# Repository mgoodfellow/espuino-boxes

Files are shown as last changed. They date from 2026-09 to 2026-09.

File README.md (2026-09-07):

# ESPuino boxes

Build profiles, wiring notes and printable enclosures for two DIY RFID audio
players built with [ESPuino](https://github.com/biologist79/ESPuino).
Insert a card, play an audiobook, and use the buttons and encoder for playback.

These are community reference builds based on physical boxes. Each profile pins
a firmware revision; compatibility with current upstream branches or other board
variants is not implied. Firmware changes live in the
[ESPuino fork’s `s3-test-all` integration branch](https://github.com/mgoodfellow/ESPuino/tree/s3-test-all),
not in this repository. The build guide starts from that fork/branch, then checks
out the exact recorded revision from the selected profile’s `upstream.lock`.
These older snapshots are retained for reproducibility; they do not follow the
current branch head automatically.

| Profile | Hardware | Storage | LEDs | Bluetooth |
|---|---|---|---|---|
| [s3-proto](boxes/s3-proto/README.md) | ESP32-S3 DevKitC-1 clone **N16R8**, 16MB flash / 8MB octal PSRAM | External SPI microSD | 12 WS2812B, NeoPixelBus LCD/GDMA | Disabled; no Classic Bluetooth |
| [kidbox-lolin-1](boxes/kidbox-lolin-1/README.md) | WeMos LOLIN D32 Pro V2.0.0, **16MB flash**, WROVER PSRAM | Onboard SPI microSD | 12 WS2812B, NeoPixelBus I2S1 | Enabled in the profile |

Both use a MAX98357A mono amplifier, RC522 reader, EC11 encoder and three
buttons. Both documented builds use a **5V USB supply**, without batteries.
The S3 also has notes for an experimental PN5180 reader swap.

## Start here

1. Choose a profile above and check its wiring against your actual board.
2. Follow the [build and first-boot guide](docs/espuino-build-guide.md).
3. Build the pinned firmware before adapting settings to another revision.
4. Try the [enclosure](case/README.md) after the electronics work on the bench.

### ESP32-S3 compilation fails on ESP32-A2DP?

The [S3 PlatformIO override](boxes/s3-proto/platformio-override.ini) sets
`lib_ignore = ESP32-A2DP`, and its settings leave `BLUETOOTH_ENABLE` disabled.
The library exclusion matters: the dependency finder can otherwise build A2DP
although the feature is disabled. The profile also supplies the N16R8 memory
configuration and a fixed toolchain URL. See the
[S3 setup and troubleshooting notes](boxes/s3-proto/README.md).

## Printable case

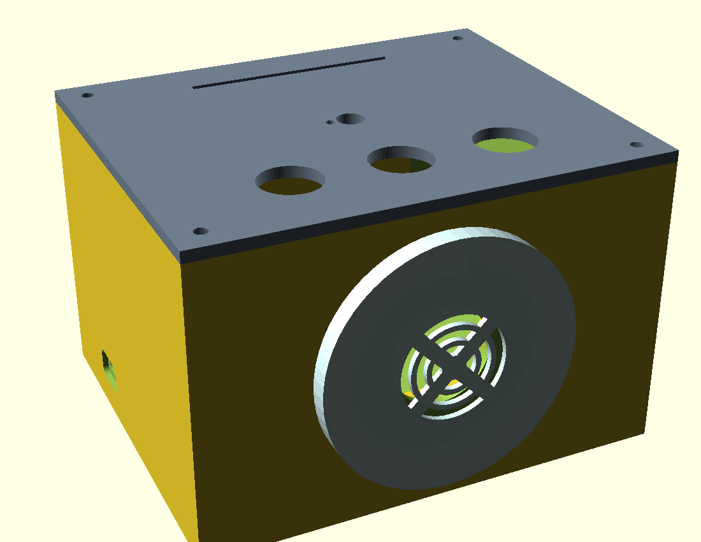
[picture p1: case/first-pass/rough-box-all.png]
CAD preview of the enclosure


The image is a CAD preview. Editable OpenSCAD and STL exports include a card
slot, speaker/ring cover, two carrier layouts and an optional RC522 offset shim.
Carrier mounts fit the measured perfboard assemblies, not bare development-board
mounting holes. Start with the fit coupon and measure your parts.

## What is included

- `boxes/`: build settings, pin maps, firmware revision locks and wiring.
- `deploy.sh`: copies one profile into a separate ESPuino checkout and builds it.
- `docs/`: build instructions and the release verification record.
- `case/`: enclosure source, exports, dimensions and fixings.

Saved Wi-Fi networks, RFID-to-audio mappings and other runtime settings live on
the device. They are not supplied here. Existing runtime settings can override
compiled defaults. Audio files are not included.

## Contributions and scope

Corrections and reports from other builds are welcome. Include the exact board,
profile, firmware commit and a redacted build/boot log. Explain what you tested
on hardware. Please keep wiring specific to a profile and avoid committing
credentials, NVS dumps or personal card mappings.

This is a hobby project, with no promised support schedule. Firmware bugs belong
upstream when reproduced there; profile and enclosure problems belong here.
See [verification and limitations](docs/VALIDATION.md) for the release evidence.

## License and credits

Released under [GNU GPL version 3](LICENSE). Configuration headers are modified
from ESPuino; see [NOTICE.md](NOTICE.md) for attribution and CAD provenance.

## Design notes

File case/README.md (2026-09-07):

# Printable enclosure

A parametric OpenSCAD enclosure with a top card slot, three 16mm buttons, EC11
encoder, speaker and 12-pixel ring. The outer shell is 124 × 102 × 78mm before
the lid and projecting cover. See [measured parts](MEASUREMENTS.md).

Assembly CAD preview

This is a practical first-pass case fitted around two specific perfboard
assemblies. Measure your parts and slice/check the model before printing.
Preview images include development views; use the selected STL and source for
actual geometry. The carrier mount patterns are not bare ESP32 board footprints.

## Files to print

| Part | File | Quantity |
|---|---|---|
| S3 shell, V1 carrier and separate SD mount | [rough-box-shell-v1.stl](first-pass/rough-box-shell-v1.stl) | 1 for S3 |
| D32 shell, V2 carrier and onboard SD | [rough-box-shell-v2.stl](first-pass/rough-box-shell-v2.stl) | 1 for D32 |
| Common lid | [rough-box-top.stl](first-pass/rough-box-top.stl) | 1 |
| Speaker/ring cover | [rough-box-cover.stl](first-pass/rough-box-cover.stl) | 1 |
| Fit coupon | [rough-box-coupon.stl](first-pass/rough-box-coupon.stl) | Print first |
| Optional RC522 offset adapter | [shim instructions](first-pass/rc522-8mm-offset-shim.md) | As needed |

Use translucent material for the cover if you want light through it. Check
orientation, overhangs, wall strength and clearances in your slicer; no universal
printer/material profile is supplied. Check card insertion and RFID reading
before committing to the full assembly.

## Editing and exporting

Open [rough-box.scad](first-pass/rough-box.scad) in OpenSCAD. Select
`part="shell"`, `"top"`, `"cover"` or `"coupon"`; for a shell select
`variant="v1"` (S3) or `"v2"` (D32). Render (F6), then export STL.
`part="all"` is an assembly preview. `variant="both"` is a legacy comparison
layout whose posts interfere with the revised V1 carrier; do not print it for a box.

The [RC522 shim source](first-pass/rc522-8mm-offset-shim.scad) exports separately.
Its offset is adjustable from 8 to 10mm; the supplied STL uses 8mm. It is an
optional retrofit, not a required part of every build.

## Assembly

1. Print the coupon and confirm screw/panel-component fits.
2. Print the appropriate shell, lid and cover.
3. Fit USB breakout, carrier and speaker with the [listed fasteners](first-pass/FIXINGS.md).
4. Slide the RC522 into the coil-end rail and secure its pin end. Use the shim
   instructions if increasing the reader-to-card gap.
5. Route wiring away from screw holes, the card guide and moving controls.
6. Test playback, controls and reliable card reading/removal before closing the lid.

These are hobby enclosure files, not a certified child-safe product. Check that
fasteners, small parts and low-voltage wiring are secured for the intended user.
See [credits and provenance](../NOTICE.md).

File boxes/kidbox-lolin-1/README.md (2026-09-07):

# LOLIN D32 Pro V2.0.0 reference build

USB-powered WeMos LOLIN D32 Pro V2.0.0 with 16MB flash, WROVER PSRAM and
onboard SPI microSD. Uses RC522, MAX98357A, a 12-pixel ring, EC11 and three buttons.

- [Build guide](../../docs/espuino-build-guide.md)
- [Wiring, resistors and wake circuit](wiring.md)
- [Firmware revision](upstream.lock): `1ea941446cd99b495cf6df2a16b6b230b3379f5a`
  from [mgoodfellow/ESPuino](https://github.com/mgoodfellow/ESPuino/commit/1ea941446cd99b495cf6df2a16b6b230b3379f5a).
- Ongoing firmware integration: [`s3-test-all`](https://github.com/mgoodfellow/ESPuino/tree/s3-test-all).
  The lock above selects an older recorded snapshot, not the moving branch head.
- Environment: `lolin_d32_pro` (`HAL=4`), not `lolin_d32_pro_sdmmc_pe`.

The profile includes the upstream HAL 4 map, then overrides the encoder switch
to GPIO22 and uses GPIO32 as a dedicated wake line. Follow the wiring table for
the external resistor and diode requirements. In particular, encoder A/B on
GPIO34/39 need pull-downs to GND; the button on GPIO36 needs a pull-up to 3V3.

Classic Bluetooth is enabled in this profile. Battery measurement and headphone
detection are disabled. LED output uses NeoPixelBus I2S1 in the pinned firmware.
Hardware wiring and fit observations are recorded in the accompanying notes;
see [release validation](../../docs/VALIDATION.md) for the current build checks.

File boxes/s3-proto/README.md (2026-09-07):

# ESP32-S3 DevKitC-1 N16R8 reference build

A USB-powered generic DevKitC-1 clone with 16MB quad flash and 8MB octal PSRAM,
SPI microSD, MAX98357A, RC522, 12-pixel WS2812B ring, EC11 and three buttons.
The directory name `s3-proto` is retained for existing deployment commands.

- [Build guide](../../docs/espuino-build-guide.md)
- [Wiring and hardware caveats](wiring.md)
- [Firmware revision](upstream.lock): `f3eec352659eb7cc195b3059cfd3d398ac1d0412`
  from [mgoodfellow/ESPuino](https://github.com/mgoodfellow/ESPuino/commit/f3eec352659eb7cc195b3059cfd3d398ac1d0412).
- Ongoing firmware integration: [`s3-test-all`](https://github.com/mgoodfellow/ESPuino/tree/s3-test-all).
  The lock above selects an older recorded snapshot, not the moving branch head.
- Environment: `esp32-s3-devkitc-1`, custom pin map (`HAL=99`).

## What the profile supplies

| Setting | Purpose |
|---|---|
| Explicit pioarduino `55.03.38-1` platform URL | Avoids the bare `espressif32` name resolving to a different toolchain |
| Pinned NeoPixelBus v2.8.4 dependency | Repairs the missing dependency declaration in the recorded firmware revision |
| `lib_ignore = ESP32-A2DP` and Bluetooth disabled | Keeps the Classic Bluetooth dependency out of S3 compilation |
| `qio_opi`, 16MB flash, `BOARD_HAS_PSRAM` | Describes this N16R8 memory arrangement |
| `CONFIG_SPIRAM_MODE_OCT=y` | Selects octal PSRAM |
| `CONFIG_SPIRAM_BOOT_INIT=y` | Initializes PSRAM before code/data placed there are used |
| `CONFIG_SPIRAM_SPEED_40M=y` | Retains the stable setting found for this particular clone |
| `custom_16mb_ota.csv` and OTA build flag | Enables both the partition layout and web OTA handler |

This firmware builds Arduino as an ESP-IDF component: `qio_opi` alone is not a
replacement for the SDK defaults. Verify about 8MB PSRAM in the boot log.
The 40MHz setting is a board-specific workaround; it does not establish that all
N16R8 boards require that speed.

## Recorded hardware experience

Development notes record successful boot, SD/audio playback, RC522 detection,
LED operation, encoder control and button wake. The pinned S3 revision was
recorded as running after web OTA in August 2026. These are historical hardware
observations; see [release validation](../../docs/VALIDATION.md) for checks run
while preparing this release.

The pinned firmware uses NeoPixelBus LCD/GDMA output for the S3 ring, retaining
FastLED animation/color math. Earlier SPI/RMT attempts encountered bus conflicts
or driver failures. Do not follow the old RMT port experiments as current setup
instructions. Use the pinned revision before experimenting with newer drivers.

Classic Bluetooth/A2DP is unavailable on this S3. Batteries, headphone detection,
4-bit SD_MMC and external Bluetooth transmitters are not validated by this profile.
The optional PN5180 wiring remains experimental.

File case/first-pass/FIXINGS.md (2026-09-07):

# Screws and fixings

Self-tapping into printed pilot holes; no heat-set inserts or nuts are required
for the documented shell. Pilots are 2.6mm for M3 and 1.6mm for M2.
Use suitable pan-head screws and check engagement before tightening.

| Screw | Quantity | Location |
|---|---|---|
| M3×10 | 4 | Lid to corner posts |
| M3×8 | 2 | USB-C breakout to side-wall ledge |
| M2×6 | 4 | Selected V1 or V2 carrier to floor posts |
| M2×6 | 2 | Speaker tabs to front bosses |
| M2×6 | 1, or 2 with optional upper screw | RC522 pin end to card-guide bosses |
| M2×6 | 4, V1 only | External SD module to left-wall posts |

Totals without the optional upper RFID screw: **M3×10 ×4, M3×8 ×2**, and
**M2×6 ×11 for V1** or **×7 for V2**. Add one M2×6 if using that upper screw.
The [offset shim](rc522-8mm-offset-shim.md) uses two M2×6 screws in total for
its reader mounting sequence, replacing the direct reader-to-shell fixing.

Only the chosen carrier pattern prints in the matching shell STL. Individual
CPU boards attach to the carrier assembly; the floor screws locate that assembly.

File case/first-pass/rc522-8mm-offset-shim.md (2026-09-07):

# RC522 8 mm offset shim

`rc522-8mm-offset-shim.stl` is a dummy-RC522 adapter for the existing
`rough-box` RFID mount. Its 60 x 39 x 1.6 mm base fits where the RC522 fitted,
then provides a new C-rail and upper mounting boss 8 mm farther into the
enclosure. The lower hole fixes the adapter to the box; the upper hole fixes
the RC522 to the adapter.

## Fitment

- Fits the existing coil-end C-rail and lower pin-side RFID boss.
- Supports the 60 x 39 mm RC522 and its 37 x 34 mm hole field.
- The SCAD `offset` can be set from 8 to 10 mm.
- Uses two standard M2x6 screws; no long screws are required.

## Installation

1. Remove the RC522 and its existing pin-side screws.
2. Drop the adapter's dummy-PCB edge into the existing coil-end C-rail.
3. Fasten the adapter's lower hole to the enclosure's lower boss with an M2x6 screw.
4. Drop the RC522 into the adapter's new C-rail.
5. Fasten the RC522's upper hole to the adapter's upper standoff with an M2x6 screw.

The STL is oriented with the dummy PCB flat for support-free printing.

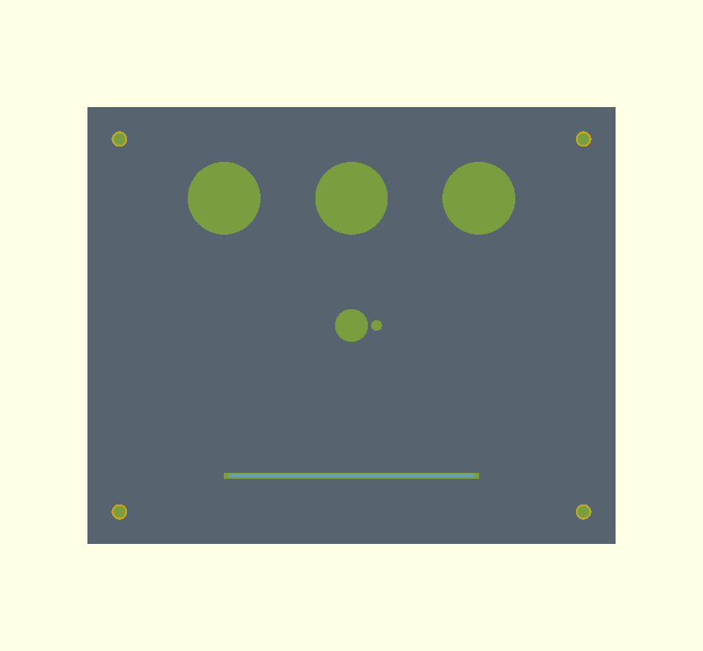
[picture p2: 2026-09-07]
case/first-pass/rough-box-toplayout.png

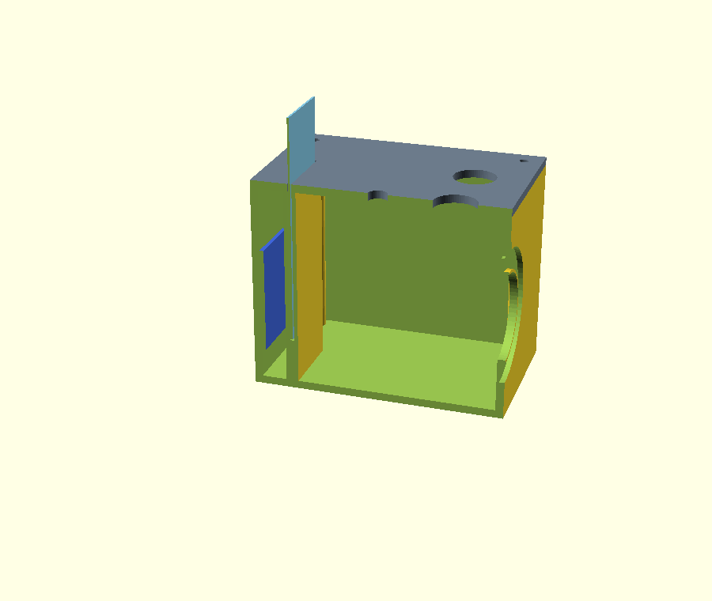
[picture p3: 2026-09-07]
case/first-pass/rough-box-section.png

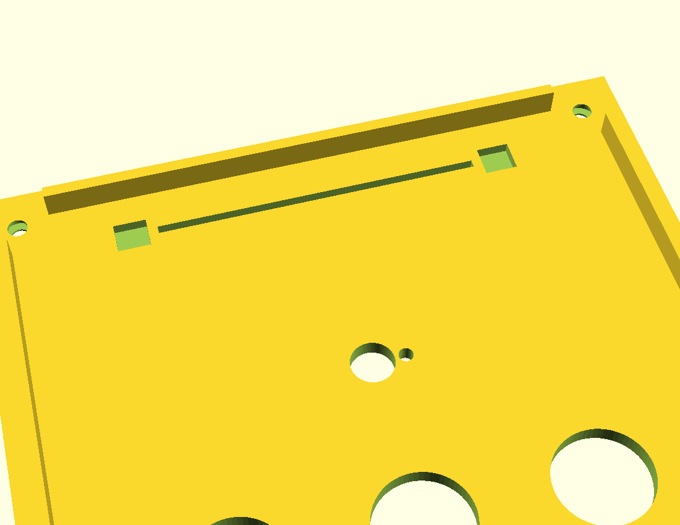
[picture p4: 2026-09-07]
case/first-pass/rough-box-lid-underside.png

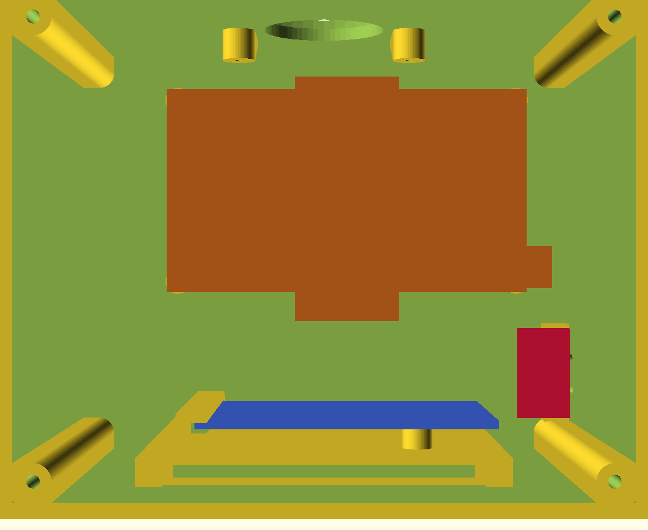
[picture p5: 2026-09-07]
case/first-pass/rough-box-layout-v2.png

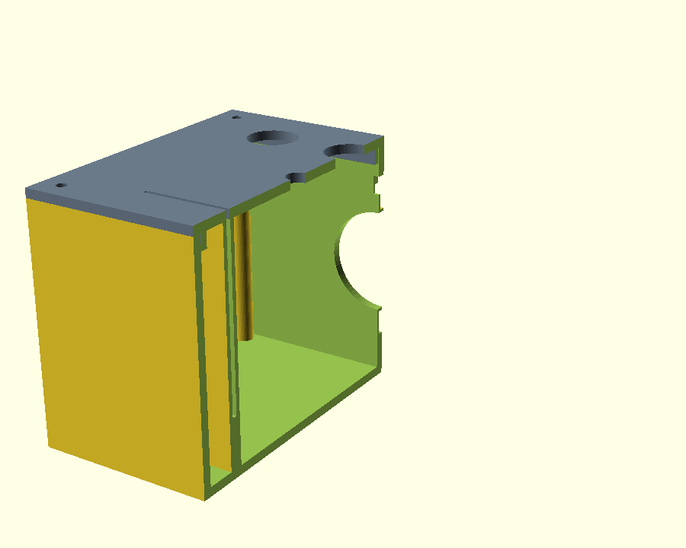
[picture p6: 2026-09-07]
case/first-pass/rough-box-lipfit.png

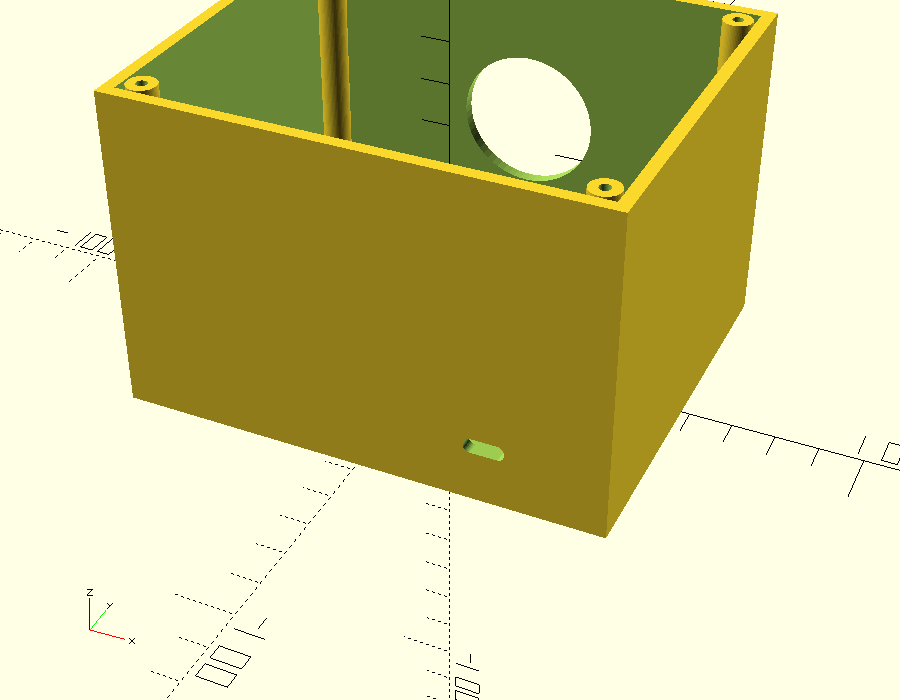
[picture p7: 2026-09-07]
case/first-pass/rough-box-shell.png

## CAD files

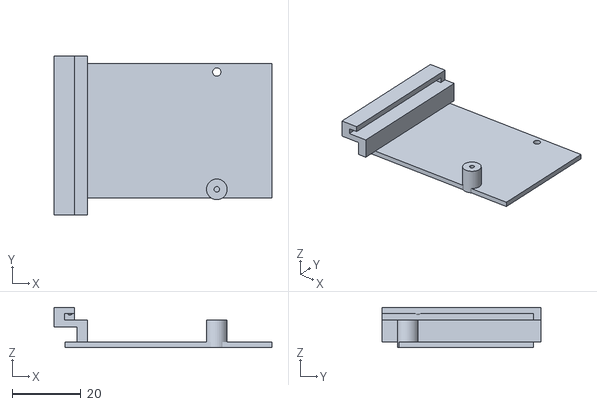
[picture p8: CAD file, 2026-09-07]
case/first-pass/rc522-8mm-offset-shim.stl
63.2 x 46.2 x 11.6

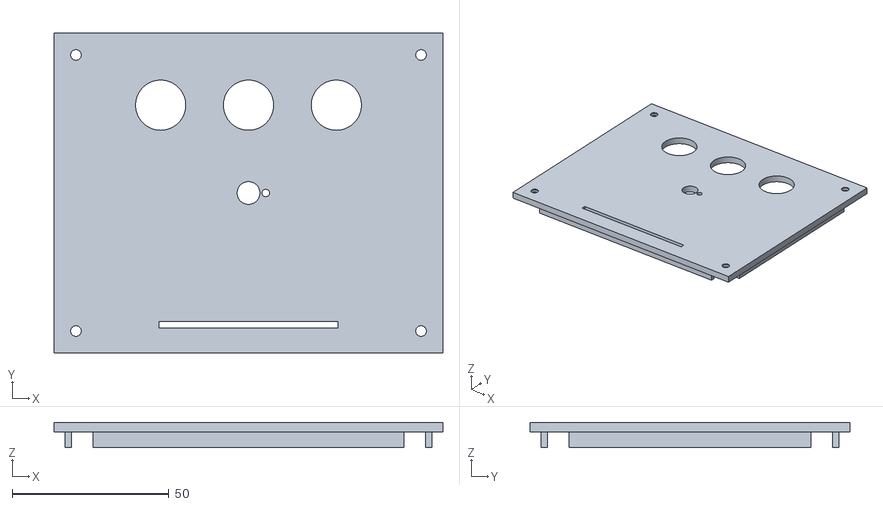
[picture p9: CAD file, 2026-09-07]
case/first-pass/rough-box-top.stl
124.0 x 102.0 x 7.98

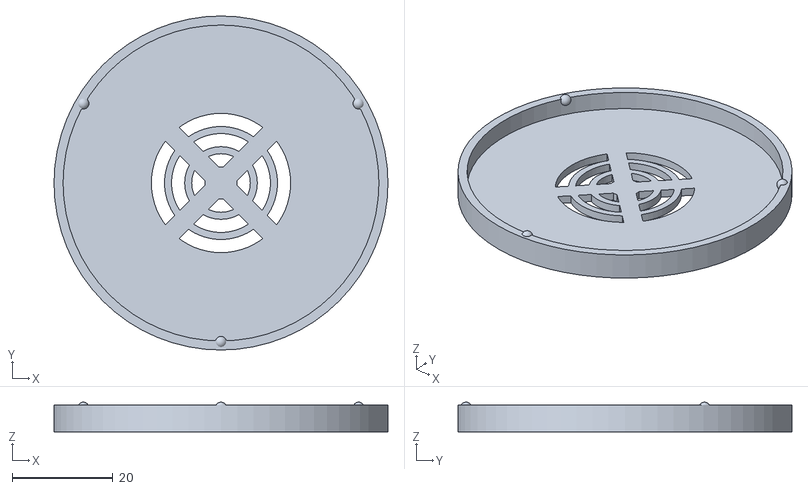
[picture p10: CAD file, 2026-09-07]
case/first-pass/rough-box-cover.stl
66.2 x 66.2 x 5.90

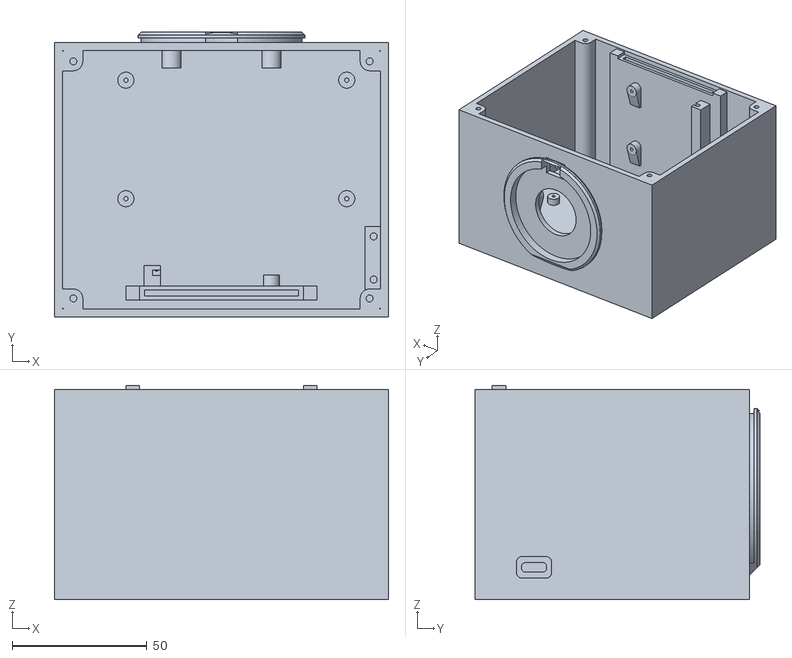
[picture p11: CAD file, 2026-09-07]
case/first-pass/rough-box-shell-v2.stl
124.0 x 106.0 x 79.6

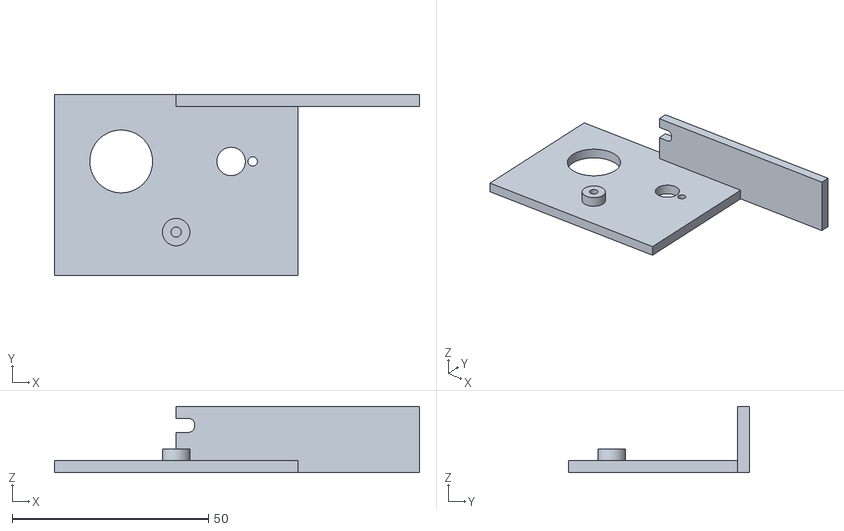
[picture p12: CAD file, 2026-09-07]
case/first-pass/rough-box-coupon.stl
93.0 x 46.0 x 16.8

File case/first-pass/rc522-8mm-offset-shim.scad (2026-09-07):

// SPDX-License-Identifier: GPL-3.0-only
// See ../../NOTICE.md and ../../LICENSE.
// RC522 retrofit offset carrier for rough-box.scad.
//
// The 1.6 mm base is a dummy RC522 PCB: it drops into the enclosure's
// existing coil-end C-rail and lands on the existing pin-side bosses. A
// second C-rail and an upper spacer boss hold the RC522 8 mm farther into
// the enclosure.
//
// Two M2x6 screws are fitted in sequence: lower hole from shim to enclosure,
// then upper hole from RC522 to shim. Print with the dummy PCB flat.

$fn = 32;

// Match the RFID mount dimensions in rough-box.scad.
board_len       = 60;
board_h         = 39;
board_t         = 1.6;
board_hole_cc_x = 37;
board_hole_cc_z = 34;
board_far_off   = 7;
board_cz        = 48;

offset          = 8;       // supported range: 8-10 mm
m2_clearance    = 2.4;
m2_pilot        = 1.6;

board_coil_x = -(board_hole_cc_x/2 + board_far_off);
board_pin_x  = board_hole_cc_x/2;
board_bottom = board_cz - board_h/2;
board_top    = board_cz + board_h/2;
lower_hole_z = board_cz - board_hole_cc_z/2;
upper_hole_z = board_cz + board_hole_cc_z/2;
eps          = 0.02;

module y_hole(d, length) {
  // Cylinder starts at the caller's y coordinate and cuts toward -Y.
  rotate([90, 0, 0]) cylinder(d=d, h=length);
}

module dummy_board() {
  difference() {
    translate([board_coil_x, 0, board_bottom])
      cube([board_len, board_t, board_h]);

    // Lower M2x6 screw fixes the dummy PCB to the enclosure's lower boss.
    translate([board_pin_x, board_t + eps, lower_hole_z])
      y_hole(m2_clearance, board_t + 2*eps);
  }
}

module upper_reader_standoff() {
  pilot_depth = 4.8;

  difference() {
    // Upper RC522 hole gets the same 6 mm boss as the original mount.
    translate([board_pin_x, 0, upper_hole_z])
      rotate([-90, 0, 0]) cylinder(d=6, h=offset);

    // Upper M2x6 screw self-taps into the shim after the RC522 is inserted.
    translate([board_pin_x, offset + board_t + eps, upper_hole_z])
      y_hole(m2_pilot, board_t + pilot_depth + 2*eps);
  }
}

module shifted_coil_rail() {
  rail_x0     = board_coil_x - 3.2;
  rail_w      = 6;
  rail_back   = 2;
  rail_bottom = board_bottom - 2.2;
  rail_top    = 72.5;
  rail_h      = rail_top - rail_bottom;
  spine_x     = board_coil_x + 3.5; // clears the old rail's inner edge
  spine_w     = 3;

  union() {
    difference() {
      // Back, end wall and front lip form the new drop-in C-channel.
      translate([rail_x0, offset - rail_back, rail_bottom])
        cube([rail_w, rail_back + board_t + 2, rail_h]);

      // 0.2 mm clearance around the RC522 edge and PCB thickness.
      translate([board_coil_x - 0.2, offset - 0.2, board_bottom])
        cube([4, board_t + 0.4, board_h + 10]);
    }

    // A narrow full-height spine rises from the dummy PCB just beyond the
    // old C-rail. The short back flange joins it to the shifted C-channel.
    translate([spine_x, board_t - eps, rail_bottom])
      cube([spine_w, offset - board_t + eps, rail_h]);
    translate([rail_x0, offset - rail_back, rail_bottom])
      cube([spine_x + eps - rail_x0, rail_back, rail_h]);

    // Match the original rail's light anti-rattle pressure on the PCB edge.
    translate([board_coil_x + 1.4, offset + board_t + 0.7, 62])
      sphere(d=1.8);
  }
}

module shim() {
  dummy_board();
  shifted_coil_rail();
  upper_reader_standoff();
}

// Rotate the installed orientation so the dummy-PCB plane prints flat.
rotate([90, 0, 0]) shim();

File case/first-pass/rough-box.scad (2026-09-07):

// SPDX-License-Identifier: GPL-3.0-only
// Parametric ESPuino enclosure; see ../README.md and ../../NOTICE.md.
// Select part = shell/top/cover/coupon for export; all is a preview.
// Select variant = v1 (S3) or v2 (D32); both is a legacy comparison only.
// Carrier mounts fit measured assemblies, not bare development boards.

part = "all";              // "coupon" | "top" | "shell" | "cover" | "all"

/* Shell VARIANT — one shell per build since 2026-07-16: the V1 board
   had to shift back 10mm (its MAX98357A overhangs the carrier front
   edge by ~15 — the y0=37 print didn't fit), which parks the shifted
   board on top of V2's back standoff row. So the posts fork:
     "v1"   -> V1 standoffs + left-wall SD mount   (s3-proto build)
     "v2"   -> V2 standoffs only                   (kidbox: SD onboard)
     "both" -> legacy shared shell (V2 back posts press on the shifted
               V1 board's solder side — preview/comparison only)      */
variant = "v1";            // "v1" | "v2" | "both"

/* ---- global fit ---------------------------------------------------- */
$fn        = 64;
clr        = 0.25;         // generic fit clearance (holes/pockets)

/* ---- box shell ----------------------------------------------------- */
box_w      = 124;          // X : left-right (was 116: grown 2026-07-10 so the
                           // 97mm carrier clears the corner posts — no clip)
box_d      = 102;          // Y : +Y FRONT, -Y BACK (was 96: grown for board
                           // runway + wire room)
box_h      = 78;           // Z : floor to wall top
wall       = 3;            // side wall thickness (rough box, not 7mm BioBox)
floor_t    = 3;

/* ---- top plate (flat lid) ------------------------------------------ */
top_t      = 3;
top_screw  = true;         // 4 corner M3 self-tap posts? (else friction)
lid_lip    = true;         // register lip under the lid -> drops into shell opening
lip_depth  = 5;            // how far the lip drops in
lip_t      = 2.0;          // lip wall thickness
lip_clear  = 0.5;          // gap to shell interior wall, per side (FIT KNOB)

/* ---- top-face layout (2026-07-07) ----------------------------
   +Y is the FRONT (speaker). Zones on the lid, front -> back:
     FRONT (+Y): 3 buttons spaced across
     CENTRE    : rotary encoder, dead-centre (0,0)
     BACK  (-Y): card slot -> card hangs by the RC522 on the back wall   */
n_buttons  = 3;            // three panel buttons; use the profile wiring table
btn_hole_d = 16.0;         // CONFIRMED: 16mm metal panel switch
btn_pitch  = 28;           // button centre-to-centre (X)
btn_y      = 28;           // button row toward FRONT (+Y, near the user)
enc_hole_d = 7.0;          // EC11 bushing ⌀7 (img 3); encoder at (0,0)
enc_tab    = true;         // keep the tab notch (harmless if the EC11 has no pin)
enc_tab_r  = 5.5;          // tab centre radius from shaft
enc_tab_d  = 2.4;

/* ---- card slot + full-height guide (Yoto-style) -------------------
   Slot near the BACK. A guide channel runs the FULL height of the shell
   (floor -> lid) so the card is captured the whole way down and can't miss
   the stop; its bottom rests at rest_z, setting how proud it stands. RC522
   sticky-pads to the back wall, coil facing the card ~1cm away (reads thru
   air). Card inserted PORTRAIT (54mm edge horizontal). Lid prints flat.   */
card_w     = 54.0;         // ISO ID-1 short edge -> slot opening width
card_t     = 0.76;         // card thickness
card_h     = 85.6;         // long edge (demo card only)
slot_w     = card_w + 3.0; // slot opening X (roomy: label wrap / edge wear)
slot_gap   = card_t + 1.2; // slot opening Y — takes a card with labels or
                           // laminate both sides (2026-07-10)
slot_y     = -42;          // slot centre near BACK (-Y): guide back face
                           // sits 3.3 off the rear wall (nothing lives
                           // behind it any more — the reader now rides the
                           // guide's FRONT face). Runway to the reader
                           // rails is ~81mm
guide_wall = 1.5;          // guide channel wall thickness
rest_z     = 20;           // card bottom rests here -> proud ~= rest_z+card_h-(box_h+top_t)
card_guide_on = true;
/* tower ends extend past the card zone as SOLID caps, each rising in a
   tab that drops into a pocket in the lid underside (2026-07-09):
   braces the tower top both ways + self-aligns lid slot to channel.  */
guide_end   = 7;           // solid end cap beyond the card zone (LEFT)
guide_end_r = 7;           // RIGHT cap (was 20 for pin-end rails; the
                           // reader's pin end is now held by a screw)
guide_tab_l = 5;           // brace tab length at each end
guide_tab_h = 1.6;         // tab rises above the wall top into the lid
guide_pock_d= 1.9;         // pocket depth in lid underside (1.1 skin above)

/* ---- main carrier boards, floor standoffs (2026-07-12) --------
   TWO stripboard variants; which standoff set prints is picked by
   `variant` (top of file) — shared-shell posts died 2026-07-16 when
   V1 shifted back onto V2's back row. All ⌀2 holes -> M2x6, 3.5 tall.

   V1 (s3-proto): ~97 x 49 rectangle, holes 93 x 39 c-c, plus an
     ~18mm speaker-wire overhang at the BACK-LEFT corner and the
     MAX98357A overhanging FORWARD off the front edge: 12 hard parts
     + ~3 speaker-cable exit = 15 envelope (caliper 2026-07-16; the
     y0=37 print hit the front wall).
     Moved back 10 -> front edge y32 (amp PCB nose y44, 4.0 off the
     wall — the last 1.0 is only cable envelope, and wire flexes;
     14-tall stack still ducks the speaker, which starts z24.5); back
     edge y-17, 1.25 clear of the USB breakout front corner (y-18.25).
     That's ALL the slack there is: the breakout can't retreat (its
     back corner y-39.75 sits 0.75 off the corner-boss web at y-40.5),
     so front-wall + breakout margins total 2.25 — split ~1/1.25. The
     back-left wire overhang ends y-35, ~5 clear of the guide face.
     Flashing USB-C pigtail STAYS PLUGGED on a SHORT edge: point it
     LEFT, under the SD module (which V1 uses). Plug adds 15 to the
     97 board (caliper, 2026-07-14) -> pattern sits +7 RIGHT of
     centre: 17.5 plug room left, 3.5 to the right wall.
     If print margins prove too thin: usbc_wall="left" would clear
     the breakout's X-zone off V1's right edge entirely (V1 left edge
     -41.5 vs left intrusion -46.5) and allow ~12mm shift with ~3mm
     margins — at the cost of the power cable exiting LEFT.
   V2 (kidbox): holes 82 x 44 c-c (board ~87 x 49), SD onboard, LOLIN
     across the middle overhanging 3 front / 7 back, terminal block
     6 out of one long edge, stack up to 30 TALL. First fit test
     (2026-07-14): set back 18 the plug did NOT fit — board now sits
     FORWARD at y0=37 (V1's old row before its 2026-07-16 shift;
     front edge ~8.5 off the wall,
     nose ducking the speaker, which starts z24.5), and the
     right-angle micro-USB lives in the ~30mm gap at the BACK,
     between the LOLIN and the card guide.
   Hole inset from board edges assumed 2.5 (V2) / 2 x 5 (V1) — nudge
   the x0/y0 pairs below if calipers disagree.                        */
main_pilot = 1.6;          // ⌀2 holes -> M2x6 self-tap
main_stand = 3.5;          // clears solder blobs under the stripboards
v1_mount_on = variant != "v2";
v1_x0      = -93/2 + 7;                  // = -39.5: +7 right of centre for
                                         // the 15mm USB-C pigtail (see above)
v1_y0      = 27;                         // was 37: back 10 for the amp
                                         // overhang (2026-07-16). Front edge
                                         // y32; back edge y-17, 1.25 off the
                                         // breakout corner — see block above
v1_cc_x    = 93;
v1_cc_y    = 39;
v2_mount_on = variant != "v1";
v2_x0      = 46.5 - 82;                  // = -35.5: fit-tested 2026-07-14
                                         // (was V1's front-right post until
                                         // V1 shifted +7 for its pigtail)
v2_y0      = 37;                         // V1's pre-shift row; plug gap
                                         // stays at the BACK (see above)
v2_cc_x    = 82;
v2_cc_y    = 44;
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

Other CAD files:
case/first-pass/rough-box-shell-v1.stl

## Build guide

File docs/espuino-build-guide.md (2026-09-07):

# Build and first boot

Start from one of the profiles in the [README](../README.md). These commands
build the revision in that profile's `upstream.lock`, including firmware changes
that may not be in the current upstream release.

## Requirements

- Linux or macOS with Bash, Git and [PlatformIO Core](https://docs.platformio.org/en/latest/core/installation/index.html).
- Several GB of free disk space and network access for the first build.
- A board matching the selected profile, a USB data cable, FAT32 microSD card,
  RC522, MAX98357A and speaker. Encoder, buttons and LEDs follow the wiring guide.
- A regulated 5V USB supply; the builds were designed around 2–3A supplies.

Use only low-voltage DC inside the enclosure. The external USB supply provides
power; there is no mains wiring inside the box. Power down before changing wires.

## Get a separate firmware checkout for each profile

From a directory where you keep projects:

```bash
git clone https://github.com/mgoodfellow/espuino-boxes.git
cd espuino-boxes

# Choose ONE profile; substitute kidbox-lolin-1 for the D32 build.
profile=s3-proto
firmware_dir="$PWD/../ESPuino-$profile"
git clone --branch s3-test-all https://github.com/mgoodfellow/ESPuino.git "$firmware_dir"
revision="$(cat "boxes/$profile/upstream.lock")"
git -C "$firmware_dir" fetch origin "$revision"
git -C "$firmware_dir" checkout --detach "$revision"

ESPUINO_DIR="$firmware_dir" ./deploy.sh "$profile" build
```

`pio` must be on PATH. Alternatively prefix the final command with
`PIO="$HOME/.platformio/penv/bin/pio"` if that is where you installed it.
The firmware source is **mgoodfellow/ESPuino**, integration branch
**[`s3-test-all`](https://github.com/mgoodfellow/ESPuino/tree/s3-test-all)**.
The clone command selects that branch explicitly, then the checkout command
selects the profile's recorded commit. It intentionally leaves a detached HEAD
at that commit. The branch may be rebased; the locked snapshots need not remain
ancestors of its latest tip, which is why the exact commit is fetched separately.

`deploy.sh` itself neither clones nor follows a remote branch: it builds whatever
commit is checked out in `ESPUINO_DIR`, warning on a lock mismatch. Its `sync`
action checks out the lock, not the current `s3-test-all` head.
The initial build downloads substantial dependencies and may take several minutes.

Keep **one firmware checkout per profile**. `deploy.sh` copies override files,
but does not remove extra files left by another profile. Reusing a checkout
can leave custom pin maps or SDK defaults from the previous build.
The script warns if the checkout differs from the profile's pinned revision;
a warning is not a compatibility check.

For the S3, the script checks that the per-target PSRAM options survived SDK
configuration generation. If needed it recopies the defaults and rebuilds once.
Use this script for the build, not a bare `pio run`.

## USB upload

After a successful build, list connected devices:

```bash
pio device list
```

Choose the port for this board. With the same `profile` and `firmware_dir`
variables as above, explicitly pass it to the upload command:

```bash
# Example only: replace this with the port from the device list.
port=/dev/ttyACM0
ESPUINO_DIR="$firmware_dir" ./deploy.sh "$profile" upload "$port"
```

This builds again and uploads via PlatformIO. It does not intentionally erase
NVS. Use the normal USB upload when provisioning a board for the first time or
changing the partition table. No upload command should run until you have
identified the correct physical device.

```bash
pio device monitor --port "$port" --baud 115200
```

## Wiring and first boot

Use the profile's wiring table, not a generic ESP32 pin diagram:

- [S3 N16R8 wiring](../boxes/s3-proto/wiring.md)
- [LOLIN D32 Pro wiring](../boxes/kidbox-lolin-1/wiring.md)

RC522 uses **3.3V**, while the documented amp and ring use **5V**. All grounds
must be connected. The external S3 SD module has its own regulator and is powered
from 5V; this does not apply to a bare 3.3V SD socket. The D32 uses its onboard slot.

1. Insert a working FAT32 microSD card. These profiles expect an SD card and reader.
2. Connect the minimal audio/RC522 hardware according to the wiring table.
3. Power up and inspect the serial log for PSRAM, SD mount and RFID detection.
4. On a device without saved Wi-Fi settings, join the `ESPuino` access point
   and open `http://192.168.4.1` to configure your own network. The compiled AP
   password is empty; provision the device on a trusted network.
5. Open its web interface using the hostname/IP shown in the boot log. Add a
   small DRM-free test audio folder and associate it with a card.
6. Check playback, then add/test the ring, encoder and buttons.
7. Validate card removal behaviour in the runtime settings before relying on
   a card-in/card-out enclosure interaction. It is not enabled by the compile-time
   `PAUSE_WHEN_RFID_REMOVED` flag in these profiles.

Keep one directory per audiobook and number chapter files consistently. Runtime
settings and card mappings are stored separately from the firmware; a reflash
does not necessarily reset them. Do not erase NVS merely to troubleshoot a build.

## OTA

After the device already has an OTA-capable partition table and firmware:

```bash
ESPUINO_DIR="$firmware_dir" ./deploy.sh "$profile" ota
```

Upload the printed **application `firmware.bin`** path using the device's web
interface (Settings → OTA). Do not upload a factory image, bootloader or partition
table there. The S3 needs both `custom_16mb_ota.csv` and
`BOARD_HAS_16MB_FLASH_AND_OTA_SUPPORT`; the profile supplies both.

## Updating a profile

New integration work belongs on `mgoodfellow/ESPuino:s3-test-all`. As checked on
2026-09-07, its head was `1a05eb639a6ce0b5cc940e7807475c8ecf20d1d5`; that is
**not** the firmware revision built in this release's verification record.
Use a separate checkout when evaluating that branch, record the exact commit,
and review the profile overrides before building.

In particular, that integration revision already declares NeoPixelBus in its
base `lib_deps`. When updating the S3 profile to it, remove the extra
`lib_deps = ${env.lib_deps}` / NeoPixelBus addition from the S3 override so the
library is not declared twice. Keep `lib_ignore = ESP32-A2DP` and the other
board-specific settings. The extra dependency remains necessary for the older
S3 revision currently in `upstream.lock`.

Keep the recorded working revision until you have tested its replacement.
Build newer firmware in another checkout, review settings compatibility, then
validate boot, storage, playback, controls, LEDs and wake/OTA as applicable on
hardware. Only then use `./deploy.sh <profile> pin` with `ESPUINO_DIR` pointing
to that checkout, and commit the lock plus any configuration changes.

`sync` checks out the existing lock; it does not fetch missing commits or update
the lock. `pin` records the checkout's HEAD; it is not hardware verification.

PlatformIO may modify tracked dependency locks or SDK configuration during a
build. Record the embedded revision from
`.pio/build/<environment>/generated/gitrevision.h`, plus the source revision and
firmware checksum, if sharing an artifact. A `-dirty` suffix must be reported.
This repository's initial release distributes profiles and CAD, not firmware binaries.

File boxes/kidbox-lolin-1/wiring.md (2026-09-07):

# kidbox-lolin-1 wiring — WeMos LOLIN D32 Pro V2.0.0

Board: LOLIN D32 Pro V2.0.0, ESP32-WROVER (PSRAM), onboard microSD slot,
16MB flash. Build env: `lolin_d32_pro` (HAL 4 with encoder-switch/wake overrides; schematic: https://www.wemos.cc/en/latest/_static/files/sch_d32_pro_v2.0.0.pdf).

## Pin map (HAL 4 plus profile overrides)

| Function | Signal | GPIO | Notes |
|---|---|---|---|
| microSD (ONBOARD — nothing to wire) | CS | 4 | hardwired: TF-CS silkscreen |
| | MOSI | 23 | shared SPI, hardwired |
| | MISO | 19 | |
| | SCK | 18 | |
| RC522 RFID (2nd SPI bus) | SCK | 14 | **3.3V only, never 5V** |
| | MOSI | 13 | |
| | MISO | 15 | |
| | CS/SDA | 21 | |
| | RST | — | leave unconnected (HAL uses dummy 99; module has onboard pull-up) |
| I2S → MAX98357A | BCLK | 27 | amp on 5V, mono, one speaker |
| | LRC/WS | 26 | |
| | DIN | 25 | |
| NeoPixel ring (12 px) | DIN | 12 | 330Ω in data line, ~1000µF across 5V, brightness ≤30–40% |
| Rotary encoder | CLK | 34 | common(middle pin)→**3V3**; 34 is input-only → external 10k **pull-DOWN to GND** (firmware forces `INPUT_PULLDOWN`, a no-op on input-only pins) |
| | DT | 39 | "VN" pin; input-only → external 10k **pull-DOWN to GND** |
| | SW | 22 | push switch (2-pin side of the encoder) → GPIO 22 + **GND**, active-low, internal pull-up — a normal button, **NOT** to 3V3 like CLK/DT. Moved off 32 so 32 can be the dedicated wake pin (see wake note) |
| Button: next | — | 33 | internal pullup OK; button to GND |
| Button: previous | — | 2 | internal pullup OK; strapping pin — button-to-GND is fine |
| Button: pause/play | — | 36 | "VP" pin; input-only, **needs external 10k pullup**; also diode-OR'd to the wake pin (see below) |
| **Wake line (diode-OR)** | — | 32 | **dedicated ext0 deepsleep-wake pin — no button on it.** 2× Schottky (anode→32, band→rotary-SW 22 *and* play/pause 36) + external **10k pull-UP 32→3V3**. Press either wake-button → 32 pulled low → wake |
| POWER (optional deepsleep transistor) | — | 5 | shares the onboard LED; fine unwired for mains build |
| Battery ADC (onboard divider) | — | 35 | built-in, feature disabled (mains build) |

**Buttons** (incl. pause/play on 36) are momentary to **GND**, active-low → the
input-only button pin (36) needs an external 10k **pull-UP** to 3V3.

**The rotary encoder is the opposite:** its common (middle) pin sits on **3V3**
and ESPuino pulls CLK/DT *down* (`pinMode(CLK/DT, INPUT_PULLDOWN)` in
RotaryEncoder.cpp — the ESP32Encoder default expects the common on 3V3). So
34/39 need external 10k **pull-DOWNs to GND**, *not* pull-ups. Common on 3V3 with
pull-UPs leaves A/B stuck high = no rotation — the classic mistake (and what the
old version of this table wrongly told you to do).

Input-only GPIOs 34/36/39 have **no internal pull resistors of either kind**,
which is why all three need an external one — pull-UP for the button, pull-DOWNs
for the encoder.

**Rotary SW (GPIO 22) — don't confuse it with the encoder's A/B.** The push
switch is a *normal button*: its 2-pin switch side goes to **GND**, active-low;
GPIO 22 (a full I/O pin) uses ESPuino's internal pull-up while awake — wire it
like next/prev, **to GND, not to 3V3**. The 3V3 side is only the encoder's
common/CLK/DT wiring. (It sat on GPIO 32 originally; moved to 22 to free 32 as
the dedicated wake pin.)

**Dual-button deepsleep wake (GPIO 32, diode-OR).** GPIO 32 is now a *dedicated*
ext0 wake pin — no button reads it, it only wakes the box. Both wake buttons feed
it through a diode, so pressing *either* wakes the box while firmware still sees
them as **separate** buttons (rotary-SW short = play/pause, long = sleep;
play/pause keeps its own action):
- **rotary-SW node (GPIO 22)** → Schottky → GPIO 32   (band/cathode toward 22)
- **play/pause node (GPIO 36)** → Schottky → GPIO 32   (band/cathode toward 36)
- **10k pull-UP GPIO 32 → 3V3** (mandatory): holds 32 high in deep sleep — ESPuino
  only re-enables an RTC pull-up for ext1, not ext0 (`Button.cpp`), so without the
  external pull-up 32 floats and wakes spuriously or misses a press.

Use **Schottky** (BAT85 / 1N5819, low Vf): a press pulls 32 to ~0.3 V, well below
the logic-low threshold. Silicon 1N4148 (~0.6 V) is marginal. The dedicated pin
means **no cross-talk** — pressing play/pause never registers as a rotary-SW press
or vice-versa. Config (already in `settings-override.h`): `ROTARYENCODER_BUTTON 22`,
`WAKEUP_BUTTON 32` (explicit — the HAL default `= ROTARYENCODER_BUTTON` would
otherwise follow the SW to 22).

## Board caveats

- **GPIO 16/17 do not exist for you** — used internally by the WROVER's PSRAM.
- **GPIO 12 is a strapping pin (MTDI)**: with the NeoPixel wired through 330Ω
  it's normally fine, but if the board bootloops with the ring attached,
  disconnect the ring's DIN at boot to confirm — known gotcha class.
- **SD_MMC mode is impossible** on this board — the onboard slot is wired to
  SPI. Don't chase MMC advice from other HALs.
- **Flash size**: env assumes 16MB (V2.0.0 spec). Some clones ship 4MB — if
  the first upload errors on partition size, check `esptool flash_id` output
  in the upload log before assuming wiring problems.
- RC522 3.3V rail only; MAX98357A and NeoPixel + SD-module-free here (onboard
  slot runs at 3.3V natively). Common ground everywhere.

## Bring-up order (see ../../docs/espuino-build-guide.md)

1. Bare board: the build guide's explicit-port upload command — boots, web UI reachable
   (AP "ESPuino" first boot), onboard SD mounts with a FAT32 card.
2. One MP3 through the MAX98357A (I2S: 27/26/25).
3. RC522: card scan shows in serial log; assign first card via web UI.
4. NeoPixel ring → encoder (with external pull-downs on A/B) → buttons.
5. Case + mains 5V 2–3A wall wart.

## Deliberate config choices (see settings-override.h)

- Bluetooth ON (Classic ESP32 has A2DP — unlike the S3 box).
- Battery measurement OFF: mains build; the onboard divider on GPIO35 floats
  without a LiPo and would throw spurious low-battery LED warnings.
- SHUTDOWN_IF_SD_BOOT_FAILS OFF: on mains, a deepsleep on SD hiccup looks like
  a dead box to a child; leave it retrying with the console alive.
- 12-LED ring (`NUM_INDICATOR_LEDS 12`).

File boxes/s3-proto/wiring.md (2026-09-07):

# s3-proto wiring — generic ESP32-S3 devkit N16R8

Board: generic ESP32-S3 DevKitC-1 clone, **N16R8** module = 16MB **quad** flash
+ 8MB **octal** PSRAM. Build env: `esp32-s3-devkitc-1` (HAL 99).

## Pin map

| Function | Signal | GPIO | Notes |
|---|---|---|---|
| SD card (SPI) | CLK | 12 | module VCC → **5V** (onboard reg needs 4.5–5.5V) |
| | MOSI | 11 | |
| | MISO | 13 | |
| | CS | 10 | |
| RC522 RFID (2nd SPI bus) | SCK | 5 | **3.3V only, never 5V** |
| | MOSI | 6 | |
| | MISO | 4 | |
| | CS | 7 | |
| | RST | 15 | |
| I2S → MAX98357A | BCLK | 16 | amp on 5V, mono, one speaker |
| | LRC/WS | 17 | |
| | DOUT | 18 | |
| NeoPixel ring | DIN | 21 | 330Ω in data line, ~1000µF across 5V, brightness ≤30–40% |
| Rotary encoder | CLK | 39 | common (middle pin) → **3V3**; pinned firmware applies INPUT_PULLDOWN |
| | DT | 40 | |
| | SW | 1 | switch (2-pin side) → GPIO 1 + GND, active-low; **RTC pin = deepsleep wake** (rewired from 41, 2026-07-05) |
| Button: next | — | 38 | |
| Button: previous | — | 42 | |
| Button: pause/play | — | 14 | **RTC pin = deepsleep wake** (rewired from 47, 2026-07-05) |

Pins **2/8/9** are reserved in the profile for the optional PN5180 IRQ/BUSY/RST.
GPIO41 is unused; GPIO47 is assigned to optional POWER control but is unwired.
Do not connect a button to a pin configured as a power-control output.
SD and RC522 are on **separate SPI buses** — the level-shifted SD module
doesn't reliably tri-state MISO.

## Reserved GPIOs on THIS board (N16R8) — never map

- **26–32** SPI flash
- **33–37** octal PSRAM extra data lines *(free on quad-PSRAM R2 boards — a
  common source of bad pinout advice; reserved here because R8 = octal)*
- **19, 20** USB-JTAG (native USB)
- **0, 3, 45, 46** strapping (46 also input-only)
- **43, 44** UART0 TX/RX
- **48** onboard RGB LED — **confirmed on 48 for this actual board**
  (2026-07-02 bare-sketch check: RGB cycles on 48, so GPIO 38 is safe for the
  NEXT button). Board also verified N16R8: eFuse reports 8MB embedded PSRAM +
  16MB quad flash; `ps_malloc(4MB)` OK; auto-reset flashing works on the COM
  port (CH343 → `/dev/ttyACM0`, ACM not ttyUSB).

## Build configuration

Follow the [S3 profile guide](README.md) and [build instructions](../../docs/espuino-build-guide.md).
This is a USB-powered build: battery measurement, headphone detection and
shutdown-on-SD-failure are disabled. Bluetooth must stay disabled.

Pause/play (GPIO14) and encoder press (GPIO1) are RTC-capable wake inputs. The
profile sets `WAKEUP_BUTTON_EXT1_MASK` for both. GPIO0 is deliberately excluded:
holding the BOOT strap low during wake can enter the serial bootloader.

## Check the clone's 5V supply routing

On the tested clone, the header marked **5V IN** was disconnected from USB VBUS
by an open IN/OUT solder jumper. The external SD module and amp had no supply
until that jumper was bridged. Other boards route power differently: identify
your board's circuit and confirm with a meter before applying this change.
On the modified board, do not simultaneously supply the 5V header externally
and connect USB; the jumper bypasses the original isolation.

## Troubleshooting from the tested build

| Symptom | What helped on this build |
|---|---|
| A2DP compile failure despite disabled Bluetooth | Add `lib_ignore = ESP32-A2DP`, as supplied by the profile |
| `NeoPixelBus.h` missing in a fresh build | Use the updated profile, which explicitly supplies the dependency omitted by its firmware pin |
| Missing PSRAM / very early boot failure | Check octal mode and boot initialization in the generated SDK config; confirm about 8MB in the boot log |
| Warm/boxed boot hang | The tested clone became reliable with PSRAM at 40MHz; the profile retains that setting |
| No SD mount / apparently dead box | Check card seating, supply and SPI wiring; inspect the boot log before assuming a failed board |
| Ring stays dark after an earlier LED-disabled build | Inspect saved runtime LED counts/brightness as well as compiled settings |
| Encoder does nothing | Check common to 3V3, A/B wiring and pull-downs; encoder press is a separate switch to GND |
| RC522 registers respond but cards are unreliable | Check supply integrity at the module; a local 470µF capacitor improved this particular assembly |
| Card detected then immediately treated as removed | Check reader/card spacing and runtime gain; gain 5 performed better than maximum gain at contact distance on the tested reader |

These are observations from one hardware stack, not diagnoses for every board.
The historical LED experiments used older FastLED/RMT paths; the pinned firmware
uses NeoPixelBus LCD/GDMA. An SD mount problem should be investigated separately
from an earlier boot hang; the serial log distinguishes them.

For the RC522 capacitor, observe polarity and use a suitable voltage rating.
Do not rely on a bulk capacitor to repair an incorrect supply or ground connection.
Test both stationary-card detection and removal with the actual cards and enclosure.
Runtime gain and pause-on-removal settings are not supplied by these source files.

## Optional PN5180 reader swap (experimental)

The pin map reserves these signals so the same second SPI bus can be used with
one reader at a time. This is a record of trial wiring, not a validated replacement
for every PN5180 module. Check the module's power requirements and pin labels.

| PN5180 signal | GPIO / supply |
|---|---|
| SCK | 5 |
| MOSI | 6 |
| MISO | 4 |
| NSS | 7 |
| BUSY | 8 |
| RST | 9 (RC522 reset uses 15 instead) |
| IRQ | 2 (optional low-power card-detection wake) |
| 5V | 5V rail on the tested module |
| 3V3 | 3.3V logic rail on the tested module |
| GND | Common ground |

Disconnect power and remove the RC522 before rewiring. Select PN5180 explicitly
in runtime settings and reboot; do not rely on auto-detection. GPIO8/9 must not
also be used for I2C: they are BUSY/RST here. This profile disables the unused
I2C-2 initialization, because earlier probing on those pins interfered with the
reader. Do not enable I2C peripherals without revisiting the pin allocation.

## Bring-up checklist

1. Inspect power routing and confirm the board really has N16R8 memory.
2. Build the pinned profile and upload to the explicitly selected port.
3. Confirm PSRAM, FAT32 SD mount and one audio file through the MAX98357A.
4. Confirm RC522 card detection and assign a test folder in the web UI.
5. Check LEDs, encoder, buttons and wake, one at a time.
6. Check runtime card-removal settings before closing the enclosure.

Related community context: [ESPuino S3 discussion](https://github.com/biologist79/ESPuino/discussions/251)
and [N16R8 build-support issue](https://github.com/biologist79/ESPuino/issues/459).

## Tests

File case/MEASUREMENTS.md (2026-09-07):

# Measured parts and fit constraints

Dimensions below were recorded during fitting in July–August 2026. They describe
the actual components used, not guaranteed dimensions for every clone. Units: mm.
The OpenSCAD source is authoritative for the exported geometry.

| Component | Recorded dimensions / mount |
|---|---|
| Shell | 124 wide × 102 deep × 78 high; wall 3; floor 3 |
| Speaker | Body 27 × 31 × 15; overall width across tabs 44; two holes 37 apart |
| WS2812 ring | 12 pixels; outer diameter 50; inner diameter 35; height 2.6 |
| Buttons | 16mm panel holes |
| EC11 | 7mm bushing hole; anti-rotation tab notch retained |
| RC522 | PCB 60 × 39; thickness 1.6; mounting field 37 along board × 34 at pin end |
| PN5180 trial board | PCB 70 × 39; check the actual hole pattern and component clearance |
| USB-C breakout | PCB 21.5 × 12.5; holes diameter 3 at 16 centres; pilot row 2.5 from wall face |
| External microSD module | PCB 24 × 42; holes diameter 2 at 20 × 38 centres |
| V1 carrier (S3) | Mount centres 93 × 39; position adjusted for USB pigtail and amp overhang |
| V2 carrier (D32) | Mount centres 82 × 44; rear gap reserved for micro-USB pigtail |

V1's amplifier and wiring project about 15mm beyond the carrier's front edge.
The revised shell moves its carrier back 10mm. Clearances around the amplifier
and USB breakout are small; a different cable or terminal block may require
editing the model. V2 has its own post layout, without the external SD mount.

Use the top card slot with the 54mm edge of an ID-1-sized card horizontal.
Check thick labels/lamination as well as bare cards. Reliable reading and removal
detection depend on the reader, card, firmware settings and distance; mechanical
fit alone does not establish RFID performance.

Before adapting: measure PCB edges, hole centres, connector overhangs, component
heights and cable bend space. Print the fit coupon before the enclosure.

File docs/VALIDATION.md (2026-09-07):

# Release verification — 2026-09-07

This record distinguishes build checks performed for public-release preparation
from earlier observations on the physical boxes. No device was flashed, no new
hardware test was performed, and no CAD geometry was changed for this release.

## Firmware source and revision policy

The integration branch is `mgoodfellow/ESPuino:s3-test-all`. Its remote head was
checked as `1a05eb639a6ce0b5cc940e7807475c8ecf20d1d5` on 2026-09-07. The
build results below apply to the profile locks, not that newer integration head.
Naming the branch explicitly in the clone instructions does not change those
locks or the validation scope.

## Firmware build checks

Builds use separate clean firmware checkouts at the profile's locked revision,
with the local PlatformIO package/download cache. This is not a test on a new OS
installation or a guarantee of byte-for-byte reproducibility across machines.

| Profile | Firmware commit | Toolchain | Result |
|---|---|---|---|
| S3 N16R8 | `f3eec352659eb7cc195b3059cfd3d398ac1d0412` | pioarduino 55.03.38-1 | PASS with the dependency repair below |
| LOLIN D32 Pro | `1ea941446cd99b495cf6df2a16b6b230b3379f5a` | pioarduino 55.03.39 | PASS |

### S3 dependency repair

The first fresh S3 build failed at `NeoPixelBus.h`: the locked firmware includes
that header but omits its library declaration. The profile now inherits
`${env.lib_deps}` and adds NeoPixelBus commit
`fd670ee534064ddf5765e4db63c213ba05bbe880` (v2.8.4), matching the dependency
in the D32 firmware. The firmware lock and hardware feature settings are unchanged.
Remove this extra declaration if a future firmware revision supplies it itself.

The repaired build passed. Its generated SDK configuration contains:

- `CONFIG_SPIRAM_MODE_OCT=y`
- `CONFIG_SPIRAM_BOOT_INIT=y`
- `CONFIG_SPIRAM_SPEED_40M=y`

Embedded revision: `f3eec35` (no `-dirty` suffix).
Application flash usage: 3,041,823 / 6,553,600 bytes.
Application binary SHA-256:
`931f7361b0ead7584fb790cfa7838001ecdfa62ecf9251a354ee464f2d57d814`.
This checksum records the local validation artifact; no firmware binary is
included in the public snapshot. Compiler warnings remain in the pinned firmware
and libraries; successful compilation is not a warning-free or hardware verdict.

### D32 result

The pinned D32 build passed with embedded revision `1ea9414` (no `-dirty`
suffix). Application flash usage: 3,450,199 / 6,553,600 bytes.
Application binary SHA-256:
`a703859ddf7e354cce0720a0914641c97c34f1667aac123bb0cfda75dde84e7c`.

During the build, PlatformIO modified `dependencies.lock` and its pre-build
script deleted the tracked `sdkconfig.defaults.esp32s3` file in this isolated D32
checkout. The embedded revision was generated while the source tree was clean.
A later build/upload can therefore embed a `-dirty` suffix unless the source
state is deliberately reconciled. Do not discard unrelated edits in a working
checkout to hide this; use a dedicated clean checkout when recording artifacts.

## Deployment script

`bash -n deploy.sh` and `python3 tests/test_deploy.py` pass. Six tests use temporary
Git repositories and a fake PlatformIO executable, without network or hardware:

- Missing upload port stops before building or copying settings.
- An explicit upload port reaches PlatformIO as a single argument.
- SDK options dropped once are restored before upload.
- Persistently missing SDK options prevent upload.
- `sync` rejects staged changes and preserves the checkout.
- `sync` accepts a clean checkout.

Upload now requires a third argument: `./deploy.sh <profile> upload <port>`.
The script still copies profile overrides into the target checkout and does not
remove files from a previously selected profile; use a separate checkout per box.

## Documentation, privacy and enclosure assets

- Superseded handoffs and personal network/device identifiers were removed from
  the public tree. A fresh publication snapshot omits the old private history.
- Local Markdown links were checked against the files in the release snapshot.
- Text was scanned for credential/key patterns and known private identifiers.
  No obvious credentials were found; the profiles retain only the intentional
  empty password for the initial ESPuino setup access point. This is a bounded
  review, not a guarantee that every possible secret format is detectable.
- PNG ancillary metadata was inspected: sRGB plus EXIF pixel dimensions, with no
  location, camera or author fields. STL files are ASCII OpenSCAD exports.
- OpenSCAD geometry is unchanged after removing comments/whitespace from the
  comparison. Existing STL exports were retained, not regenerated or newly printed.
  OpenSCAD was not available for a fresh render during this preparation.

## Hardware evidence and limits

The original development notes record S3 boot, PSRAM, SD/audio, RC522, LED,
encoder, button-wake and OTA observations, plus D32 wiring/fit work. They do not
constitute new hardware verification of this release. In particular, the S3
fresh-build dependency repair has not been re-flashed and checked on hardware.

PN5180 remains experimental. Other clones, batteries, headphone detection,
4-bit SD_MMC and current upstream firmware branches are outside this validation.
The main intended use is a reproducible starting point for the documented boards.

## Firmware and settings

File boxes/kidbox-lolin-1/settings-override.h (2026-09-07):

// SPDX-License-Identifier: GPL-3.0-only
// Based on ESPuino configuration, copyright its contributors.
// Modified for these box profiles in 2026; public preparation 2026-09-07.
// See ../../NOTICE.md and ../../LICENSE.
// clang-format off
// ============================================================================
// kidbox-lolin-1 — ESPuino settings for WeMos LOLIN D32 Pro V2.0.0
// Copied into ESPuino/src/settings-override.h by deploy.sh.
// Pin map = upstream's tested settings-lolin_d32_pro.h (HAL 4), included at
// the bottom, with encoder-switch and wake overrides below the include.
// Wiring details and external resistor requirements are in wiring.md.
// ============================================================================

#ifndef __ESPUINO_SETTINGS_OVERRIDE_H__
    #define __ESPUINO_SETTINGS_OVERRIDE_H__
        #include "Arduino.h"
        #include "values.h"

	//################## HARDWARE-PLATFORM ###############################
	#ifndef HAL             // Set by platformio.ini (env lolin_d32_pro -> -DHAL=4)
		#define HAL 4
	#endif

	//########################## MODULES #################################
	//#define PORT_EXPANDER_ENABLE
	//#define I2S_COMM_FMT_LSB_ENABLE       // Don't enable for MAX98357a
	#define MDNS_ENABLE                     // Reach the box via ESPuino.local
	//#define MQTT_ENABLE
	#define FTP_ENABLE                      // Activate after boot: PAUSE + NEXT in parallel
	#define NEOPIXEL_ENABLE                 // classic-ESP32 WS2812 now goes through NeoPixelBus (I2S1 method)
	                                        // since 2026-07-09 — FastLED's WS2812 backend aborts on this
	                                        // Arduino-3.3.8/IDF-5.5 stack (no free SPI host; SD+RC522 own
	                                        // HSPI/VSPI). See Led.cpp + this box's platformio-override.ini.
	//#define NEOPIXEL_REVERSE_ROTATION
	#define LANGUAGE EN
	#define PLAY_MONO_SPEAKER               // One MAX98357A, one speaker
	//#define HEADPHONE_ADJUST_ENABLE       // No headphone PCB / HP-detect wired
	//#define SHUTDOWN_IF_SD_BOOT_FAILS     // OFF during bring-up (keeps console alive on
	                                        // SD trouble). This box is mains-powered, so a
	                                        // dead-looking deepsleep on SD failure is worse
	                                        // than a retry loop; reconsider if battery added.
	//#define MEASURE_BATTERY_VOLTAGE       // Mains-powered, no battery fitted. The onboard
	                                        // divider on GPIO35 floats without a battery ->
	                                        // spurious low-battery Neopixel warnings.
	                                        // Enable if a LiPo goes in later.
	//#define MEASURE_BATTERY_MAX17055
	//#define SHUTDOWN_ON_BAT_CRITICAL
	//#define PLAY_LAST_RFID_AFTER_REBOOT
	#define USEROTARY_ENABLE
	#define BLUETOOTH_ENABLE                // Classic ESP32 has BT-Classic; A2DP works here
	                                        // (unlike the S3 box)
	//#define IR_CONTROL_ENABLE
	//#define PAUSE_WHEN_RFID_REMOVED
	//#define DONT_ACCEPT_SAME_RFID_TWICE
	//#define HALLEFFECT_SENSOR_ENABLE

	#ifdef PAUSE_WHEN_RFID_REMOVED
		#define ACCEPT_SAME_RFID_AFTER_TRACK_END
	#endif

	//################## select SD card mode #############################
	//#define SD_MMC_1BIT_MODE              // NOT possible on D32 Pro — onboard slot is
	                                        // hardwired to SPI (23/19/18, CS 4)
	//#define SINGLE_SPI_ENABLE
	//#define NO_SDCARD

	//################## select RFID reader ##############################
	// Reader type is chosen at RUNTIME since #403 (web UI / serial / NVS).
	// 0 = auto-detect, 1 = MFRC522 (SPI), 2 = MFRC522 (I2C), 3 = PN5180
	#define RFID_READER_TYPE_RUNTIME 0    // Auto-detect (finds the RC522 on SPI)

	#if defined(RFID_READER_TYPE_RUNTIME)
		#define MFRC522_ADDR 0x28           // default I2C-address of MFRC522
	#endif

	//############# Port-expander-configuration ######################
	#ifdef PORT_EXPANDER_ENABLE
		constexpr uint8_t expanderI2cAddress = 0x20;
	#endif

	//################## BUTTON-Layout ##################################
	// 0: NEXT_BUTTON  1: PREVIOUS_BUTTON  2: PAUSEPLAY_BUTTON
	// 3: ROTARYENCODER_BUTTON  4: BUTTON_4  5: BUTTON_5
	// *****BUTTON*****        *****ACTION*****
	#define BUTTON_0_SHORT    CMD_NEXTTRACK
	#define BUTTON_1_SHORT    CMD_PREVTRACK
	#define BUTTON_2_SHORT    CMD_PLAYPAUSE
	#define BUTTON_3_SHORT    CMD_PLAYPAUSE   // battery-measure disabled on this box
	#define BUTTON_4_SHORT    CMD_NOTHING
	#define BUTTON_5_SHORT    CMD_NOTHING

	#define BUTTON_0_LONG     CMD_LASTTRACK
	#define BUTTON_1_LONG     CMD_FIRSTTRACK
	#define BUTTON_2_LONG     CMD_PLAYPAUSE
	#define BUTTON_3_LONG     CMD_SLEEPMODE
	#define BUTTON_4_LONG     CMD_NOTHING
	#define BUTTON_5_LONG     CMD_NOTHING
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

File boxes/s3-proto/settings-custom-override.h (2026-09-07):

// SPDX-License-Identifier: GPL-3.0-only
// Based on ESPuino configuration, copyright its contributors.
// Modified for these box profiles in 2026; public preparation 2026-09-07.
// See ../../NOTICE.md and ../../LICENSE.
// clang-format off
// ============================================================================
// s3-proto pin map — generic ESP32-S3 devkit N16R8
// Copied into ESPuino/src/settings-custom-override.h by deploy.sh; included
// from settings-override.h (HAL 99). Full rationale + wiring in wiring.md.
//
// NEVER map these GPIOs on an N16R8:
//   26-32  SPI flash
//   33-37  octal PSRAM extra data lines (free on quad-PSRAM R2 boards — do not
//          trust R2 pinout advice on this board)
//   19,20  USB-JTAG (native USB)
//   0,3,45,46  strapping (46 also input-only)
//   43,44  UART0 TX/RX (keep for serial)
//   48     onboard RGB LED (left free on purpose; some revs use 38 — confirm,
//          ours uses 38 for the NEXT button!)
// Spare free pins: 1, 2, 8, 9, 14
// ============================================================================

#ifndef __ESPUINO_SETTINGS_CUSTOM_OVERRIDE_H__
#define __ESPUINO_SETTINGS_CUSTOM_OVERRIDE_H__
    #include "Arduino.h"

    //################## GPIO-configuration ##############################
    // ESP32-S3 note: unlike classic ESP32 there are no input-only pins in use
    // here (only GPIO46 is input-only on S3) and the GPIO matrix routes any
    // signal to any pin.

    #ifdef SD_MMC_1BIT_MODE
        #error "s3-proto uses SD via SPI; SD_MMC pin set not defined for this board yet (stretch goal)"
    #else
        // uSD-card-reader (via SPI) — FSPI-native pins, fastest bus.
        // SD module VCC -> 5V (module has its own regulator + level shifter).
        #define SPISD_CS                    10          // GPIO for chip select (SD)
        #ifndef SINGLE_SPI_ENABLE
            #define SPISD_MOSI              11          // GPIO for master out slave in (SD)
            #define SPISD_MISO              13          // GPIO for master in slave out (SD)
            #define SPISD_SCK               12          // GPIO for clock-signal (SD)
        #endif
    #endif

    // RFID-reader RC522 (via SPI, second/bit-banged bus — kept separate from SD
    // because the level-shifted SD module doesn't reliably tri-state MISO).
    // RC522 on 3.3V ONLY — never 5V.
    #define RST_PIN                         15          // RC522 reset
    #define RFID_CS                         7           // GPIO for chip select (RFID)
    #define RFID_MOSI                       6           // GPIO for master out slave in (RFID)
    #define RFID_MISO                       4           // GPIO for master in slave out (RFID)
    #define RFID_SCK                        5           // GPIO for clock-signal (RFID)

    #if defined(RFID_READER_TYPE_RUNTIME)
        // Only used if runtime RFID detection probes for a PN5180 — mapped to
        // spare pins so probing never touches anything wired.
        #define RFID_BUSY                   8           // PN5180 BUSY
        #define RFID_RST                    9           // PN5180 RESET
        #define RFID_IRQ                    2           // PN5180 IRQ (LPCD only)
    #endif

    // I2S (DAC) -> MAX98357A (on 5V, mono, one speaker)
    #define I2S_DOUT                        18          // Digital out (I2S)
    #define I2S_BCLK                        16          // BCLK (I2S)
    #define I2S_LRC                         17          // LRC/WS (I2S)

    // Rotary encoder
    #ifdef USEROTARY_ENABLE
        //#define REVERSE_ROTARY                        // To reverse encoder's direction
        #define ROTARYENCODER_CLK           39          // rotary encoder's CLK
        #define ROTARYENCODER_DT            40          // rotary encoder's DT
    #endif

    // Amp enable (optional) — not wired on s3-proto
    //#define GPIO_PA_EN                    112
    //#define GPIO_HP_EN                    113

    // Control-buttons (99 = DISABLE; 0->47 GPIO; 100->115 port-expander)
    // PAUSEPLAY + encoder SW sit on RTC-capable pins (0-21) so they can wake
    // the box from deepsleep (rewired 47->14 and 41->1).
    #define NEXT_BUTTON                     38          // Button 0
    #define PREVIOUS_BUTTON                 42          // Button 1
    #define PAUSEPLAY_BUTTON                14          // Button 2 (RTC pin, deepsleep wake)
    #define ROTARYENCODER_BUTTON            1           // Button 3 (encoder SW, RTC pin, deepsleep wake)
    #define BUTTON_4                        99          // unused
    #define BUTTON_5                        99          // unused

    //#define BUTTONS_LED                   114

    #ifdef PORT_EXPANDER_ENABLE
        #define PE_INTERRUPT_PIN            99
    #endif
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
